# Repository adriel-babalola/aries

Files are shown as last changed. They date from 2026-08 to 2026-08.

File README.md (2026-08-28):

# Aries: Compact CO2 Air Quality Sensor

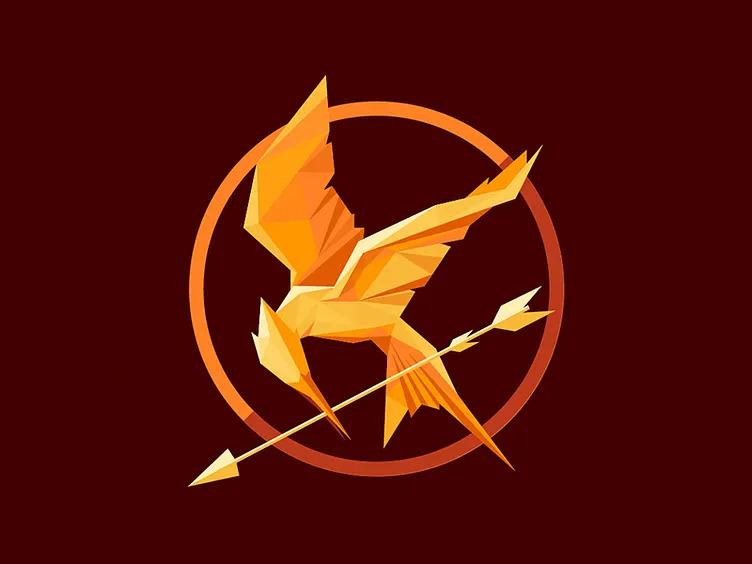
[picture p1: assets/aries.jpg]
Aries LOGO







**Aries** is a compact, battery-powered air quality monitoring device that measures CO₂ levels via a beautiful circular 1.28" TFT display. Built around the **Seeed Studio XIAO ESP32-C3**, it features the Sensirion **SCD40** CO₂ sensor and displays real-time air quality data with WiFi/Bluetooth connectivity.

Went for the name aries beacause i thought it was the Egyptian god of the Air, tunred out the actual name i was looking for was Horus, but i was already in too deep, so i went with Aries.

## Features

- **Real-time CO₂ Monitoring**: Sensirion SCD40 sensor with high accuracy (±50 ppm over 400–2000 ppm)
- **Display**: 1.28" circular GC9A01 TFT display (240×240)
- **Portable**: Runs on a 3.7V LiPo battery (1000 mAh)
- **Smart Power Management**: Slide switch for manual on/off without desoldering
- **Wireless**: WiFi + Bluetooth (BLE 5.0) via ESP32-C3 for data logging or mobile app integration
- **PCB**: 2-layer design optimized for component placement
- **3D-Printed Enclosure**: Base and Lid

## Hardware Overview

### Core Components

| Component | Model | Purpose |
|---|---|---|
| **Microcontroller** | Seeed XIAO ESP32-C3 | Brain of the device; manages display & sensor |
| **CO₂ Sensor** | Sensirion SCD40-D-R2 | Measures atmospheric CO₂ (I2C interface) |
| **Display** | GC9A01 1.28" TFT | Circular 240×240 RGB display (SPI) |
| **Battery** | 3.7V 1000 mAh LiPo | Portable power (503450 or 603040 form factor) |
| **Power Switch** | Slide/Toggle | On/off control on battery line |

### PCB Design

**Schematic**
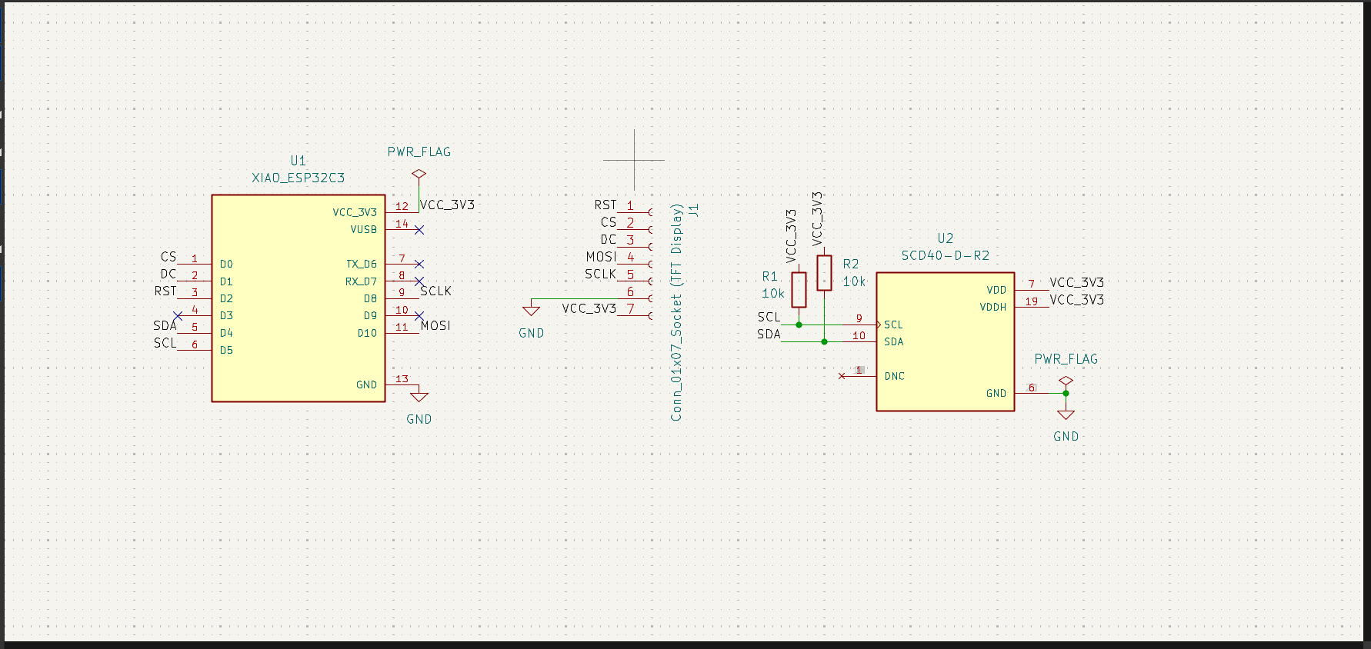
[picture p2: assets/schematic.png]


**PCB**
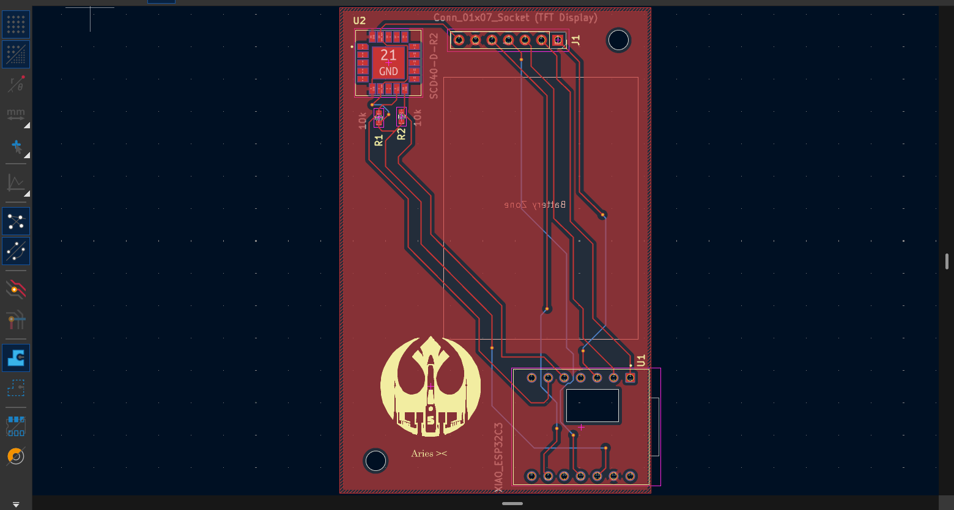
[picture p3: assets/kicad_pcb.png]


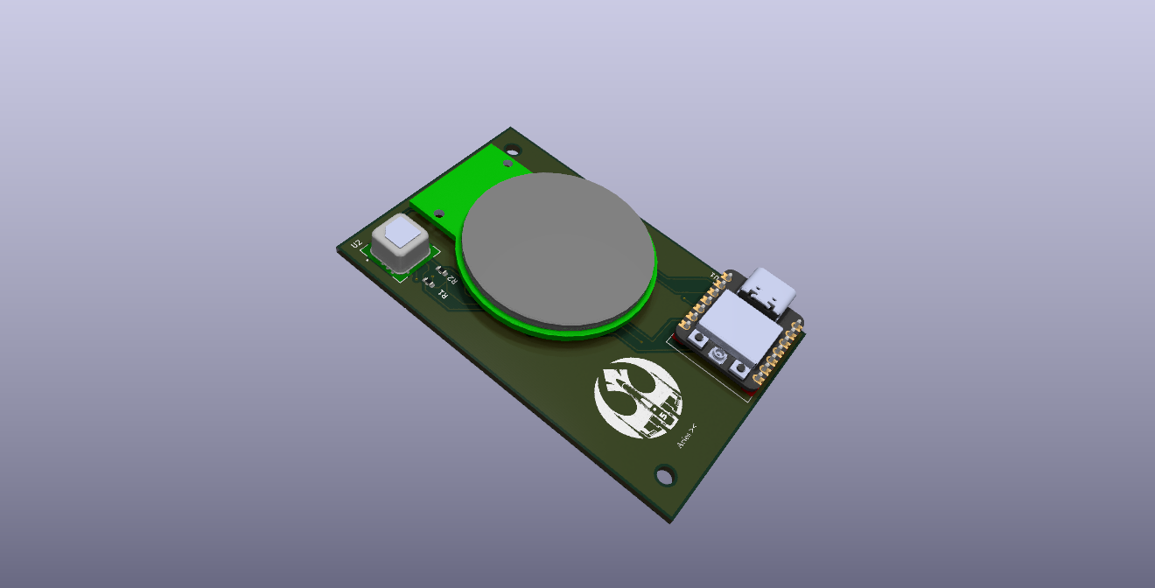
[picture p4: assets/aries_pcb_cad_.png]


### Case Design

The enclosure consists of three 3D-printed parts:

1. **Case** (`aries_casing_full.f3z`): Main body that houses the PCB and display

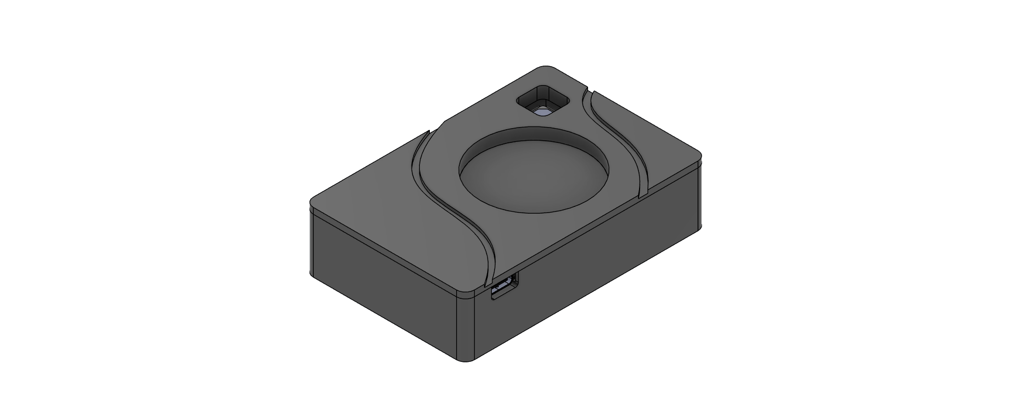
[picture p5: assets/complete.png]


2. **Base** (`base.f3z`): Bottom mounting plate
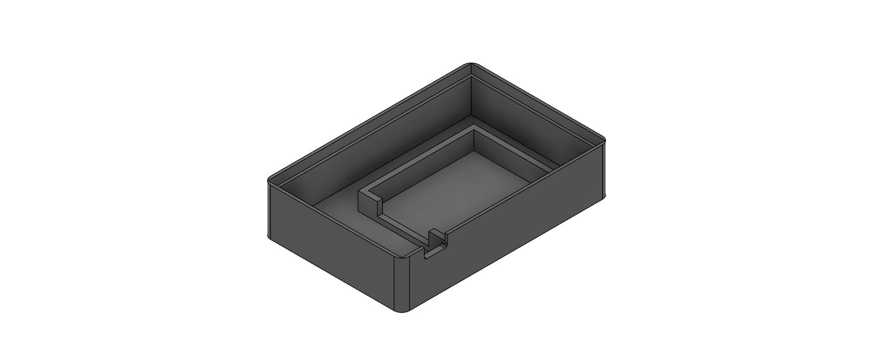
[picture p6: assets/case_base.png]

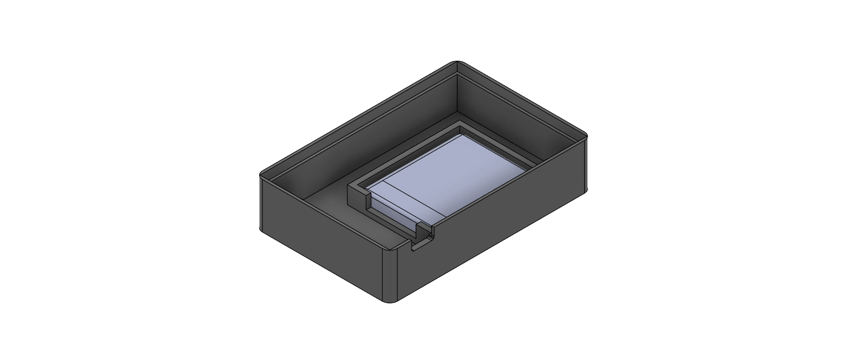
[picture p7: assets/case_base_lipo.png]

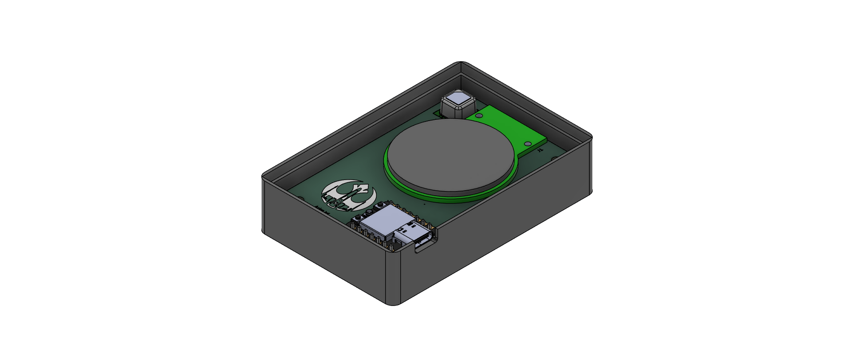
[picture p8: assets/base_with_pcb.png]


3. **Lid** (`lid.f3z`): Top cover with display cutout
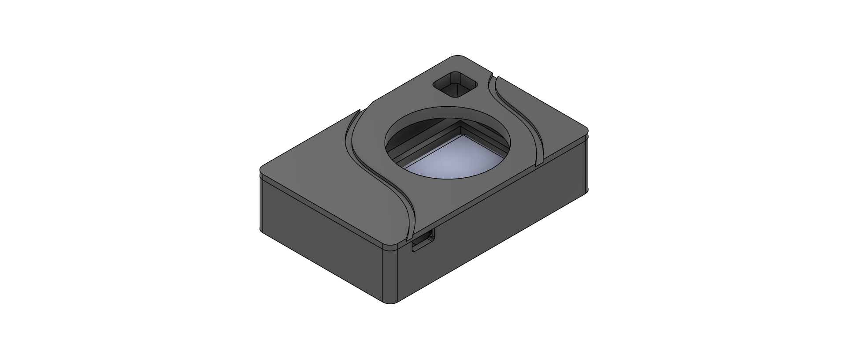
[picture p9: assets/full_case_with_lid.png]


## Bill of Materials

| Component | Value | Qty | Supplier | Original Price | Final Price |
|---|---|-----|---|---|---|
| PCB + PCBA (SCD 40) | 5 PCB + 2 PCBA | 7 | [PCBWay](https://www.pcbway.com/) | $72.48 | $72.48 |
| Xiao ESP32-C3 | — | 1 | [Seeed Studio Store](https://www.aliexpress.com/item/1005007039705247.html?spm=a2g0o.cart.0.0.3c3838da85i9NG&mp=1) | $10.77 | $4.63 |
| LiPo Battery | 3.7V 1000mAh | 1 | [Rainpro Store](https://www.aliexpress.com/item/1005005244012524.html?spm=a2g0o.cart.0.0.3c3838da85i9NG&mp=1) | $4.40 | $3.34 |
| Power Switch | SS12D06G5 3-Pin | 1 | [DQLZV Store](https://www.aliexpress.com/item/1005006258365679.html?spm=a2g0o.cart.0.0.3c3838da85i9NG&mp=1) | $1.42 | $1.39 |
| Circular TFT Display | 1.28" GC9A01 | 1 | [Shenzhen Chip Store](http://aliexpress.com/item/1005005925857858.html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) | $3.92 | $2.42 |
| M2.5 Screws | 10mm x50pc | 1 | [ScrewMax Supply Store](https://www.aliexpress.com/item/1005012931823427.html?spm=a2g0o.cart.0.0.3c3838da85i9NG&mp=1) | $1.63 | $1.60 |
| Soldering Wire | 50g 0.6mm | 1 | [JCD Official Store](https://www.aliexpress.com/item/1005006030104628.html?spm=a2g0o.cart.0.0.3c3838da85i9NG&mp=1) | $2.37 | $2.30 |
| AliExpress Shipping | — | — | [AliExpress](https://www.aliexpress.com/) | — | $8.69 |
| **TOTAL COST** | | | | | **$106.50** |

### Display Guide

A full guide to working with the GC9A01 circular display and ESP32-C3 is available here:  
🔗 [Bench: XIAO ESP32-C3 + 1.28" Circular TFT](https://thesolaruniverse.wordpress.com/2024/04/02/bench-featuring-a-seeed-studio-xiao-esp32-c3-and-a-1-28-spi-gc9a01-circular-tft-display/)

## Inspiration & References

This project draws from several open-source projects and guides:

- **Seeed Studio** - XIAO ESP32-C3 ecosystem and examples
- **Sensirion** - SCD40 sensor datasheet and Arduino library
- **@notaroomba** - GitHub README structure and best practices
- **@GarageTinkering** - 3D CAD enclosure design tutorial ([YouTube](https://www.youtube.com/@GarageTinkering))
- **The Solar Universe Blog** - GC9A01 display integration guide

and may the Odds ever be in your favor

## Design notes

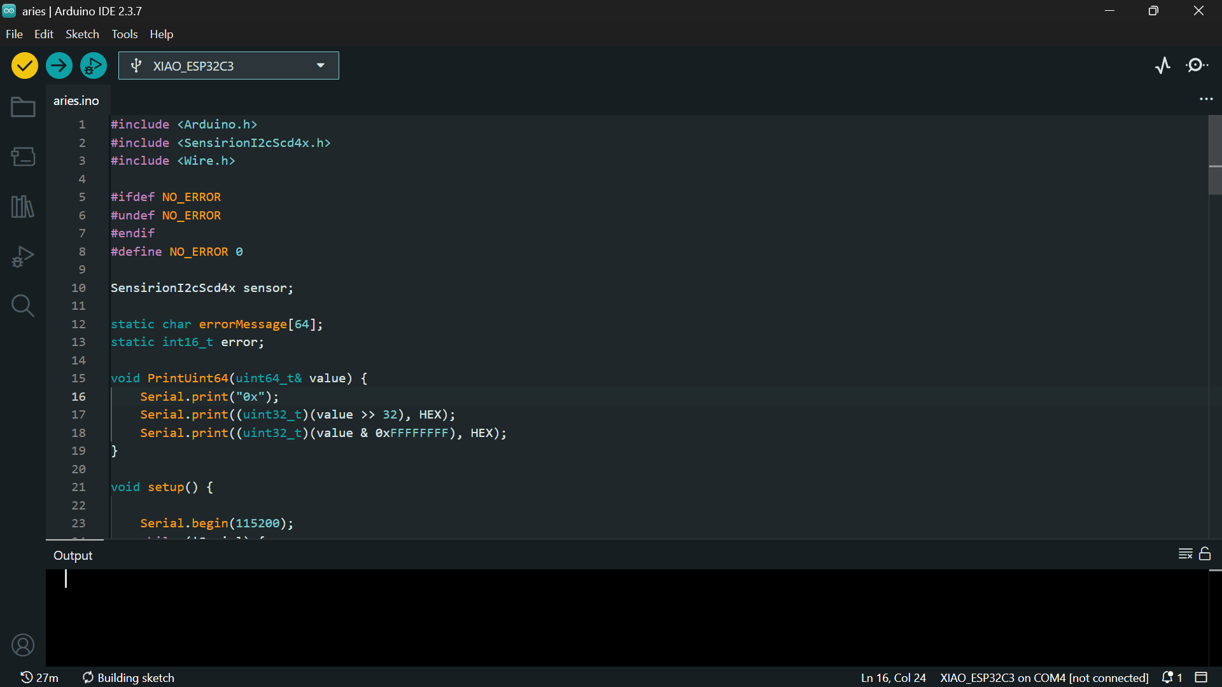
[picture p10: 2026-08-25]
assets/code.png

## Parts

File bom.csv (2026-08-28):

Component | Value | Qty | Supplier | Original Price | Final Price
PCB + PCBA (SCD 40) | 5 PCB + 2 PCBA | 7 | https://www.pcbway.com/ | 72.48 | 72.48
Xiao ESP32-C3 | — | 1 | https://www.aliexpress.com/item/1005007039705247.html?spm=a2g0o.cart.0.0.3c3838da85i9NG&mp=1 | 10.77 | 4.63
LiPo Battery | 3.7V 1000mAh | 1 | https://www.aliexpress.com/item/1005005244012524.html?spm=a2g0o.cart.0.0.3c3838da85i9NG&mp=1 | 4.40 | 3.34
Power Switch | SS12D06G5 3-Pin | 1 | https://www.aliexpress.com/item/1005006258365679.html?spm=a2g0o.cart.0.0.3c3838da85i9NG&mp=1 | 1.42 | 1.39
Circular TFT Display | 1.28" GC9A01 | 1 | http://aliexpress.com/item/1005005925857858.html?mp=1 | 3.92 | 2.42
M2.5 Screws | 10mm x50pc | 1 | https://www.aliexpress.com/item/1005012931823427.html?spm=a2g0o.cart.0.0.3c3838da85i9NG&mp=1 | 1.63 | 1.60
Soldering Wire | 50g 0.6mm | 1 | https://www.aliexpress.com/item/1005006030104628.html?spm=a2g0o.cart.0.0.3c3838da85i9NG&mp=1 | 2.37 | 2.30
AliExpress Shipping | — | — | https://www.aliexpress.com/ | — | 8.69
TOTAL COST |  |  |  |  | 106.50

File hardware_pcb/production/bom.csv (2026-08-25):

Designator | Footprint | Quantity | Value | LCSC Part #
R1, R2 | 0603 | 2 | 10k
U2 | XDCR_SCD40-D-R2 | 1 | SCD40-D-R2

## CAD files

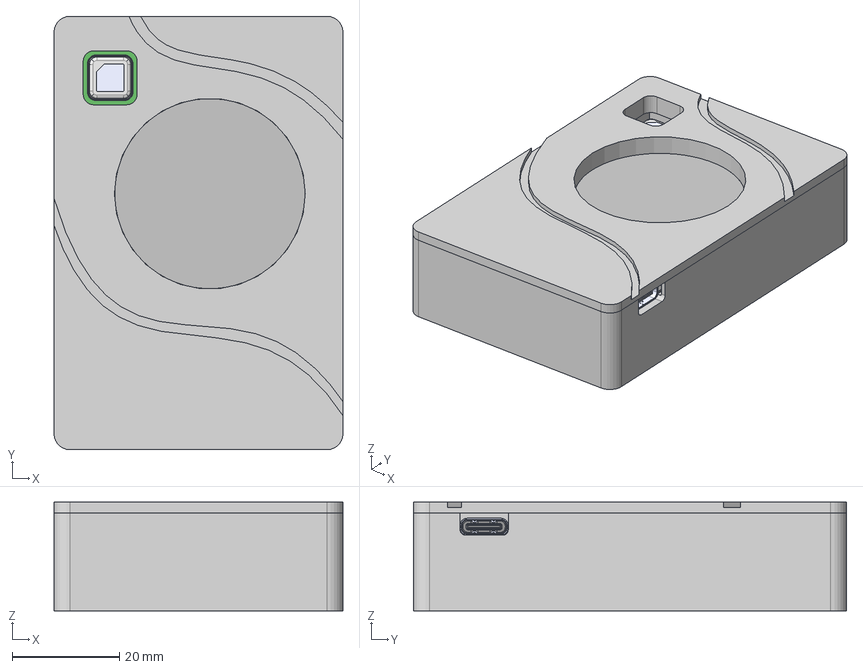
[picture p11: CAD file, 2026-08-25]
3d_cad/aries_casing_full.step
54.0 x 81.0 x 20.3 mm

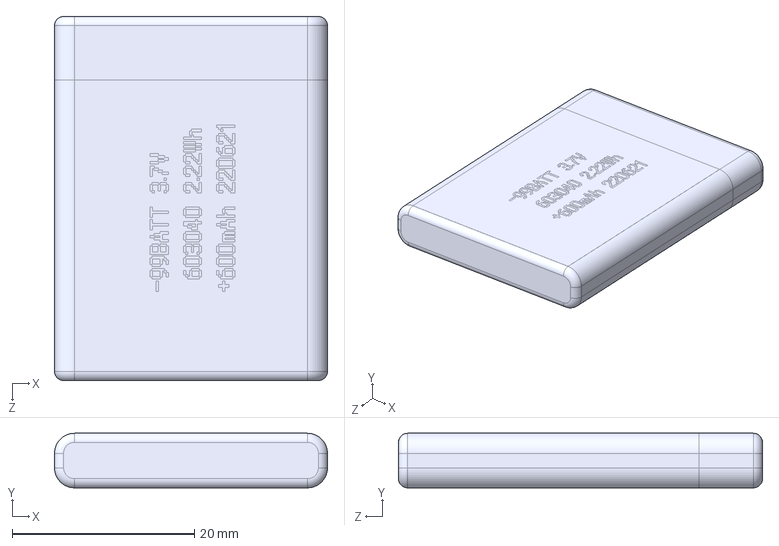
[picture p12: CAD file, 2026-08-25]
3d_cad/lipo.STEP
30.0 x 6.01 x 40.0 mm

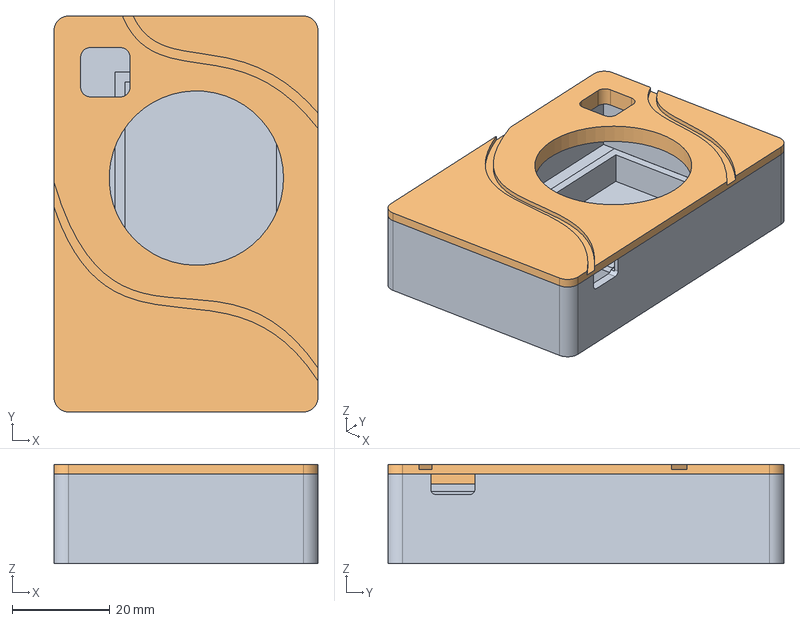
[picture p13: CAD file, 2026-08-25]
3d_cad/base.step
54.0 x 81.0 x 20.3 mm

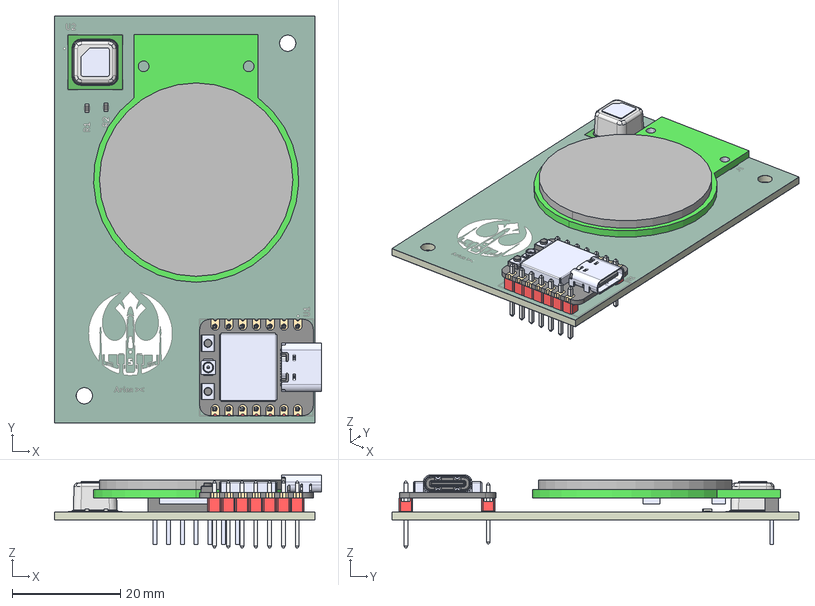
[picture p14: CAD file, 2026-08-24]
3d_cad/aries_pcb_new.step
49.2 x 75.0 x 13.4 mm
100mill Male Pin Header_7P_R x 2
1.28 TFT GC9A01 Display
R_0603_1608Metric x 2
149693-00_SCD4x_Datasheet
aries_silkscreen x 2
aries_soldermask x 2
aries_PCB

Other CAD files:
3d_cad/lid.step
3d_cad/aries_casing_full.f3z
3d_cad/base.f3z
3d_cad/lid.f3z

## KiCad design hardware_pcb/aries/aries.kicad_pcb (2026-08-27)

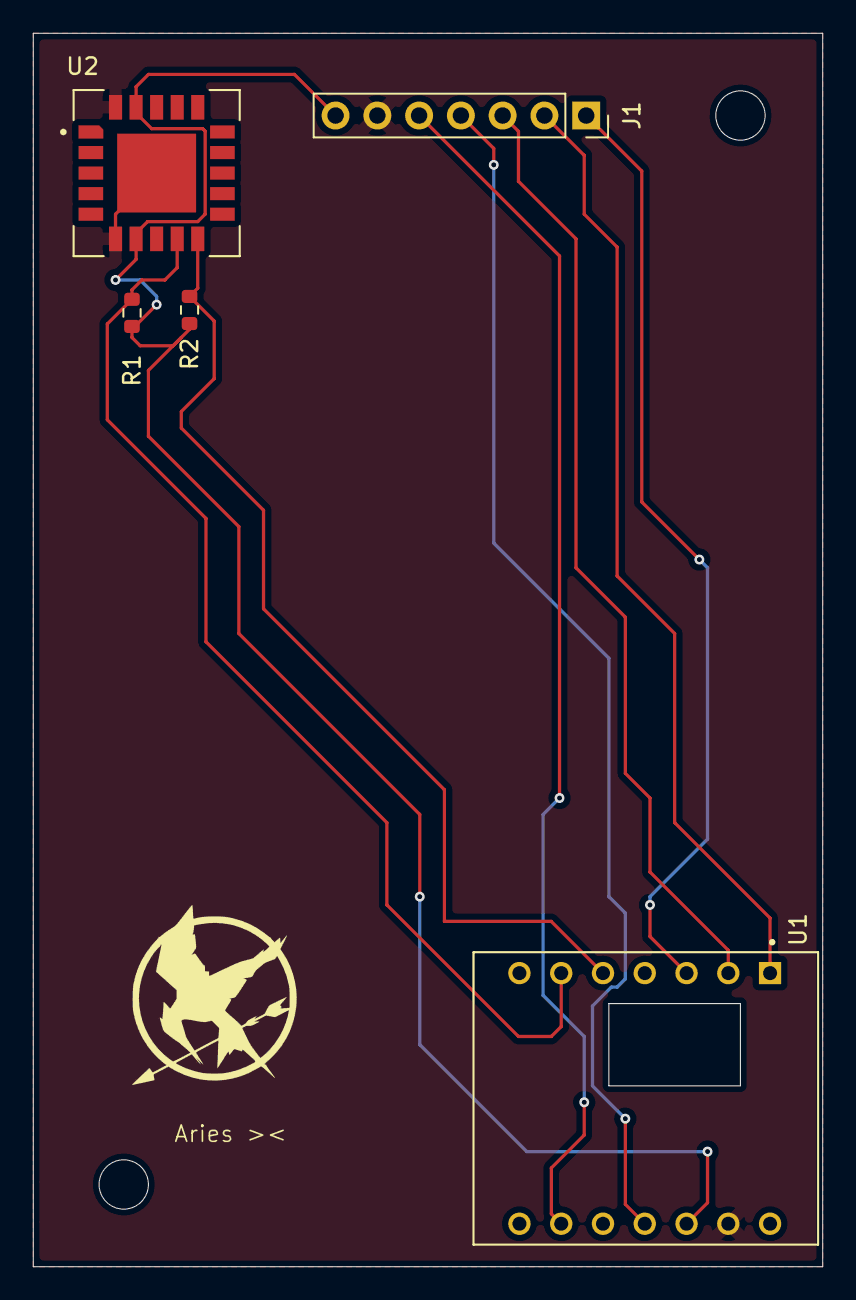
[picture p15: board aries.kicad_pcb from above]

Board: 2 copper layers, 48.0 x 75.0 mm, 5 parts (0 on the bottom side), 9 nets.

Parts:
J1: Conn_01x07_Socket (TFT Display); PinSocket_1x07_P2.54mm_Vertical
R1, R2: 10k; R_0603_1608Metric
U1: XIAO_ESP32C3; MODULE_XIAO_ESP32C3
U2: SCD40-D-R2; XDCR_SCD40-D-R2

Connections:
/CS: J1.2, U1.1 (D0)
/DC: J1.3, U1.2 (D1)
/MOSI: J1.4, U1.11 (D10)
/RST: J1.1, U1.3 (D2)
/SCL: R1.2, U1.6 (D5), U2.9 (SCL)
/SCLK: J1.5, U1.9 (D8)
/SDA: R2.2, U1.5 (D4), U2.10 (SDA)
/VCC_3V3: J1.7, R1.1, R2.1, U1.12 (VCC_3V3), U2.7 (VDD), U2.19 (VDDH)
GND: J1.6, U1.13 (GND), U2.6 (GND), U2.20 (GND), U2.21 (GND)

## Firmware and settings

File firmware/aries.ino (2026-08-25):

#include <Arduino.h>
#include <SensirionI2cScd4x.h>
#include <Wire.h>

#ifdef NO_ERROR
#undef NO_ERROR
#endif
#define NO_ERROR 0

SensirionI2cScd4x sensor;

static char errorMessage[64];
static int16_t error;

void PrintUint64(uint64_t& value) {
    Serial.print("0x");
    Serial.print((uint32_t)(value >> 32), HEX);
    Serial.print((uint32_t)(value & 0xFFFFFFFF), HEX);
}

void setup() {

    Serial.begin(115200);
    while (!Serial) {
        delay(100);
    }
    Wire.begin();
    sensor.begin(Wire, SCD41_I2C_ADDR_62);

    uint64_t serialNumber = 0;
    delay(30);

    error = sensor.wakeUp();
    if (error != NO_ERROR) {
        Serial.print("Error trying to execute wakeUp(): ");
        errorToString(error, errorMessage, sizeof errorMessage);
        Serial.println(errorMessage);
    }
    error = sensor.stopPeriodicMeasurement();
    if (error != NO_ERROR) {
        Serial.print("Error trying to execute stopPeriodicMeasurement(): ");
        errorToString(error, errorMessage, sizeof errorMessage);
        Serial.println(errorMessage);
    }
    error = sensor.reinit();
    if (error != NO_ERROR) {
        Serial.print("Error trying to execute reinit(): ");
        errorToString(error, errorMessage, sizeof errorMessage);
        Serial.println(errorMessage);
    }
    // Read out information about the sensor
    error = sensor.getSerialNumber(serialNumber);
    if (error != NO_ERROR) {
        Serial.print("Error trying to execute getSerialNumber(): ");
        errorToString(error, errorMessage, sizeof errorMessage);
        Serial.println(errorMessage);
        return;
    }
    Serial.print("serial number: ");
    PrintUint64(serialNumber);
    Serial.println();
  

    error = sensor.startPeriodicMeasurement();
    if (error != NO_ERROR) {
        Serial.print("Error trying to execute startPeriodicMeasurement(): ");
        errorToString(error, errorMessage, sizeof errorMessage);
        Serial.println(errorMessage);
        return;
    }


}

void loop() {

    bool dataReady = false;
    uint16_t co2Concentration = 0;
    float temperature = 0.0;
    float relativeHumidity = 0.0;
    //
    // Slow down the sampling to 0.2Hz.
    //
    delay(5000);
    error = sensor.getDataReadyStatus(dataReady);
    if (error != NO_ERROR) {
        Serial.print("Error trying to execute getDataReadyStatus(): ");
        errorToString(error, errorMessage, sizeof errorMessage);
        Serial.println(errorMessage);
        return;
    }
    while (!dataReady) {
        delay(100);
        error = sensor.getDataReadyStatus(dataReady);
        if (error != NO_ERROR) {
            Serial.print("Error trying to execute getDataReadyStatus(): ");
            errorToString(error, errorMessage, sizeof errorMessage);
            Serial.println(errorMessage);
            return;
        }
    }
   
    error =
        sensor.readMeasurement(co2Concentration, temperature, relativeHumidity);
    if (error != NO_ERROR) {
        Serial.print("Error trying to execute readMeasurement(): ");
        errorToString(error, errorMessage, sizeof errorMessage);
        Serial.println(errorMessage);
        return;
    }
 

    Serial.print("CO2 concentration [ppm]: ");
    Serial.print(co2Concentration);
    Serial.println();
    Serial.print("Temperature [°C]: ");
    Serial.print(temperature);
    Serial.println();
    Serial.print("Relative Humidity [RH]: ");
    Serial.print(relativeHumidity);
    Serial.println();
    
}

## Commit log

2026-08-22 aries pcb done
    [aries.kicad_pcb, aries.kicad_sch]
2026-08-24 PCB done
    [aries.kicad_pcb, aries.step, lipo.STEP]
2026-08-24 new cad
    [aries_new.step]
2026-08-25 CAD complete
    [aries_casing_full.f3z, aries_casing_full.step, aries_pcb_new.step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]
2026-08-25 images and rename
    [aries.kicad_pcb, aries.kicad_sch, aries_casing_full.f3z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]
2026-08-25 readme v1
    [bom.csv, designators.csv, positions.csv]
2026-08-25 adjusted some things
    [bom.csv]
2026-08-26 completed with correct quote
    [bom.csv]
2026-08-27 changed to the mocking jay
    [aries.kicad_pcb, positions.csv]
2026-08-28 updated bom, changed to scd 40 r1
    [bom.csv]
